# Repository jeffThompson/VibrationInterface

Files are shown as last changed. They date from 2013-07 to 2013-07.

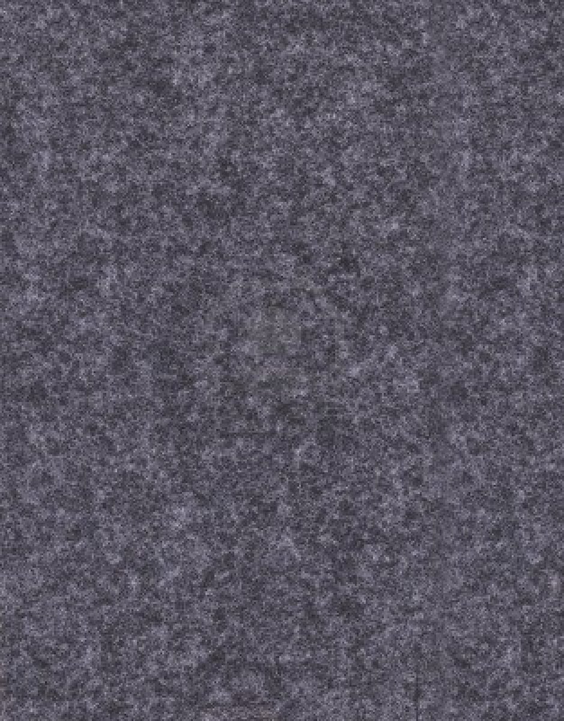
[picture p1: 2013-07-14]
LasercutPartsCADFiles/CAD_Model/FeltTexture.jpg

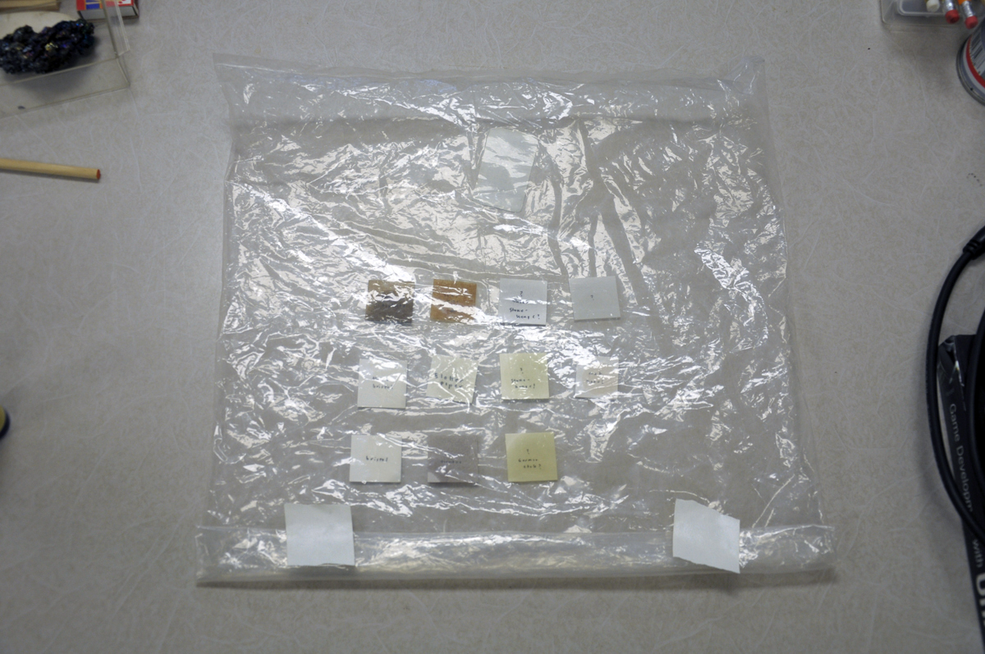
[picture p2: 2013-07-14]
ProcessPhotos/ScentImpregnationTest-02.jpg

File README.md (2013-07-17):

Vibration Interface

Vibration Interface
==================

A vibration interface for the Arduino, with example applications.

1. `LasercutPartsCADFiles` includes all files for building the interface, with files for cutting using Ponoko.
2. `LevelGenerationTimeTest` is a small app for testing how quickly the Arduino can generate a 2d array and randomly walk through it - used to optimize the included Mesa game.
3. `Mesa` is an example application for the interface where a player navigates an algorithmically-generated mesa, avoiding the cliff's edge.
4. `ProcessPhotos` includes documentation of the development process for this project.
5. `Simon` is a similar to the classic game of the same name, where the player must match an ever-lengthening pattern of directions. Instead of colored lights and sounds, this game uses the four vibration directions.

For required parts, see the `VibrationInterface_BOM.csv` and open in Excel (or a text editor), or [view the latest version in Google Docs](https://docs.google.com/spreadsheet/ccc?key=0ApWbqo450AfRdGZGZERDV3J2ZkhOYmNZS2k5c2tVR1E#gid=0).

Created with generous assistance from Harvestworks' Cultural Innovation Fund program.

\- \- \-

\[ all resources available under [Creative Commons BY-NC-SA license](http://creativecommons.org/licenses/by-nc-sa/3.0/) - feel free to use but [please let me know](http://www.jeffreythompson.org) \]

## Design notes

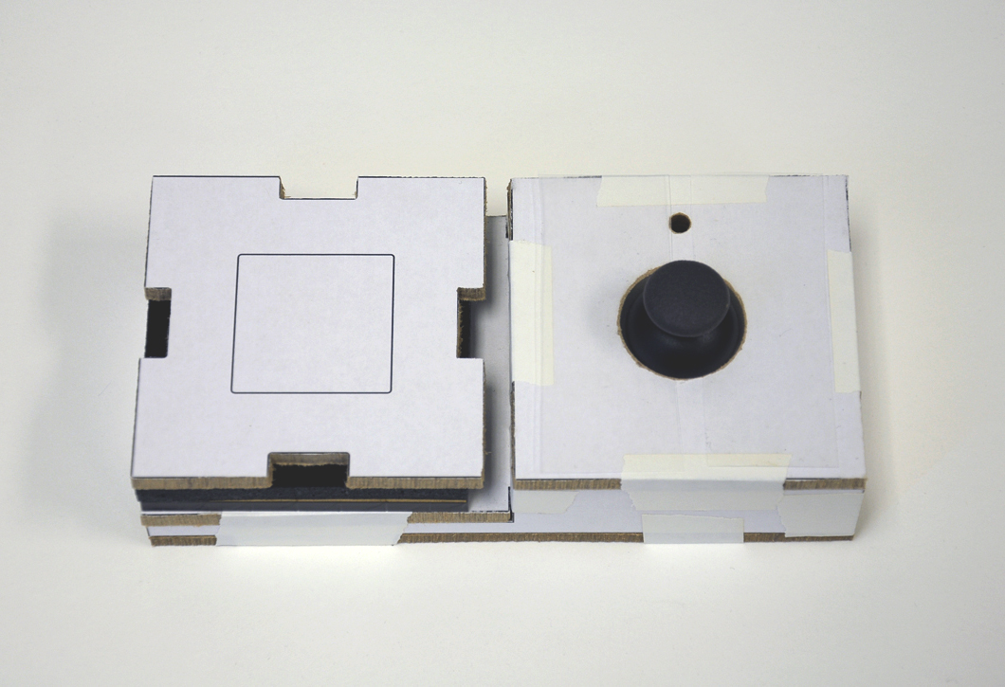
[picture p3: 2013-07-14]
ProcessPhotos/VibeBoard_WithInterface.jpg

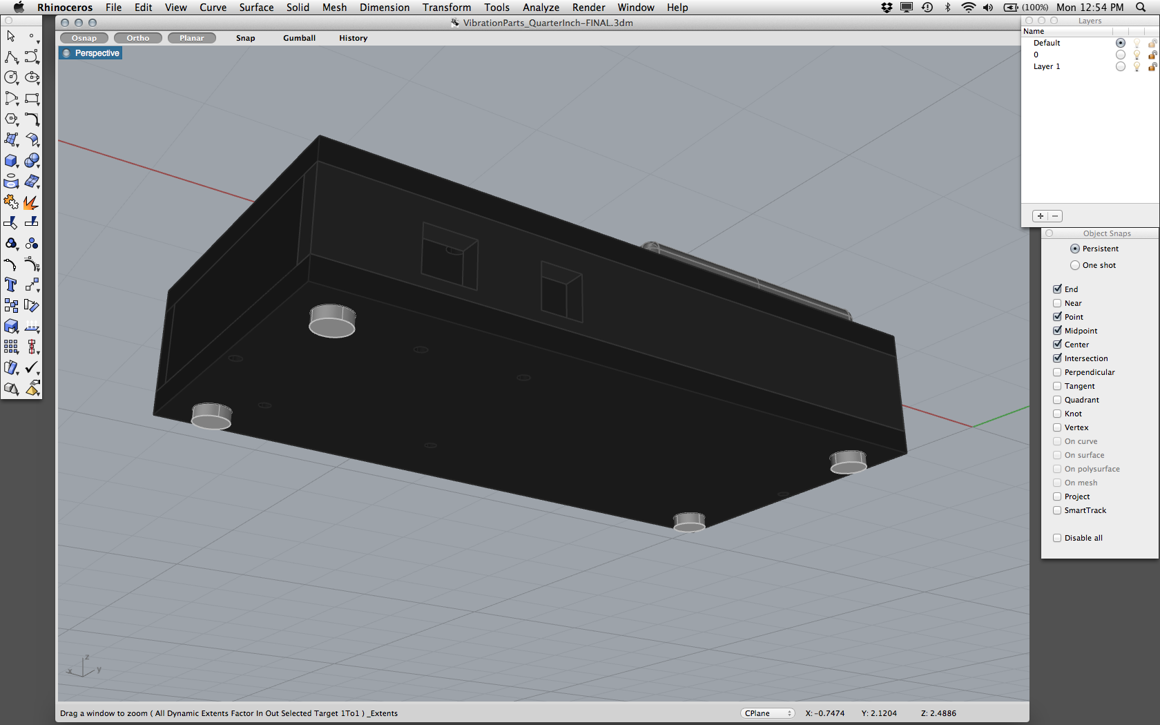
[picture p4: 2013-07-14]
ProcessPhotos/Final3dModel_Bottom.png

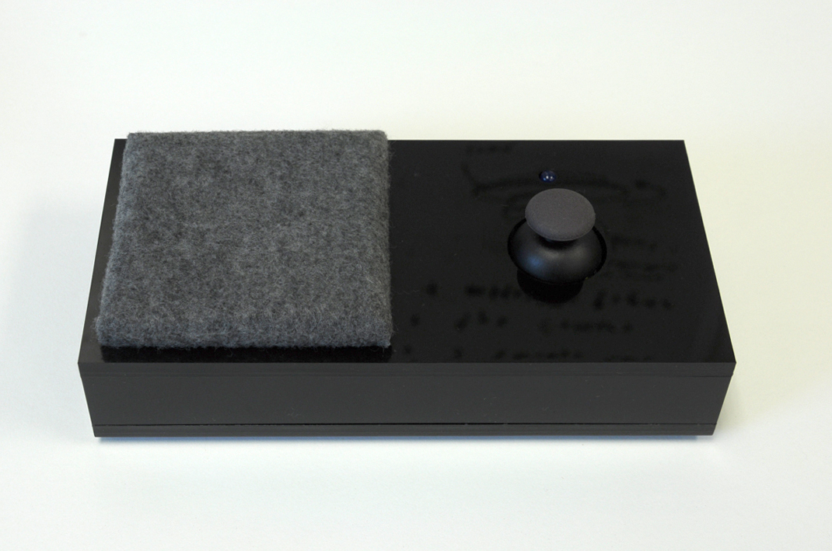
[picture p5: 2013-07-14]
ProcessPhotos/FinalPrototype.jpg

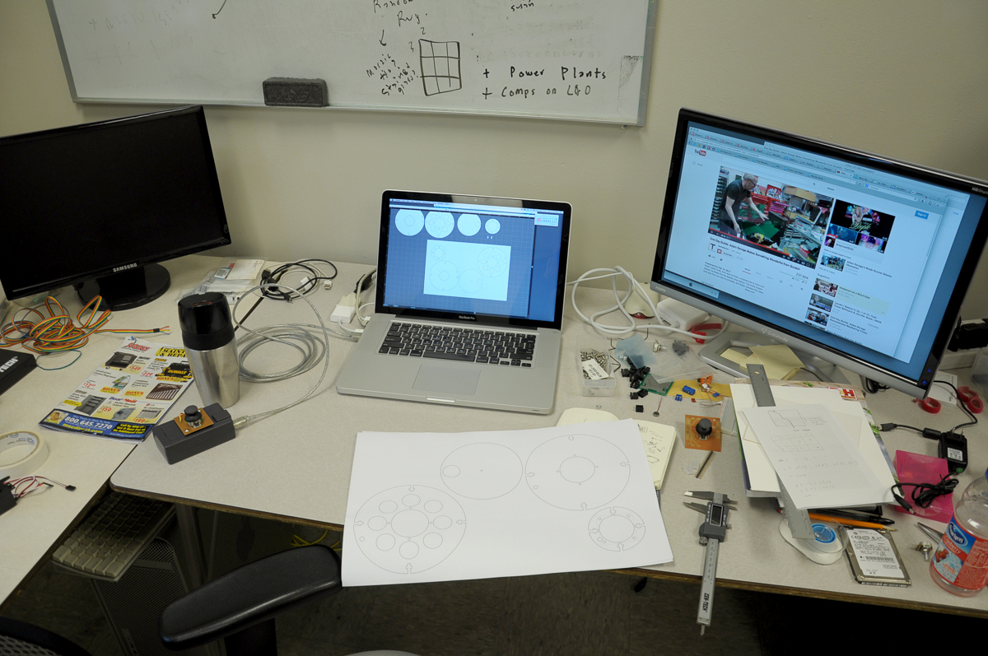
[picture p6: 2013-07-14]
ProcessPhotos/StudioInProcess.jpg

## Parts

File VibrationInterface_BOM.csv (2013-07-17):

Exported from a Google Doc: https://docs.google.com/spreadsheet/ccc?key=0ApWbqo450AfRdGZGZERDV3J2ZkhOYmNZS2k5c2tVR1E#gid=0
DESCRIPTION | $ EA | QTY | $ TOTAL | VENDOR | PART # | URL
Thumb joystick | $3.95 | 1 | $3.95 | SparkFun | COM-09032 | https://www.sparkfun.com/products/9032
Ribbon cable, 6 wire, 15 feet | $2.95 | 1 | $2.95 | SparkFun | CAB-10646 | https://www.sparkfun.com/products/10646
5mm blue LED | $0.50 | 1 | $0.50 | SparkFun | COM-11372 | https://www.sparkfun.com/products/11372
Breakaway male header (straight) | $1.50 | 2 | $3.00 | SparkFun | PRT-00116 | https://www.sparkfun.com/products/116
Arduino (lasercut parts designed for Uno, but Leonardo will work too) | $29.95 | 1 | $29.95 | SparkFun | DEV-11021 | https://www.sparkfun.com/products/11021
USB A/B cable | $3.95 | 1 | $3.95 | SparkFun | CAB-00512 | https://www.sparkfun.com/products/512
Clear heatshrink tubing, 1/8" x 4' | $4.19 | 1 | $4.19 | Digikey | KY018C-ND | http://www.digikey.com/scripts/DKSearch/dksus.dll?Detail&itemSeq=129182024&uq=635016143281570651
Vibration motor, flat coin | $3.99 | 4 | $15.96 | Digikey | 28821-ND | http://www.digikey.com/scripts/DKSearch/dksus.dll?Detail&itemSeq=129182080&uq=635016143281570651
Resistor (SMD 1210, 10k) - for button and/or standalone Arduino | $0.33 | 1 | $0.33 | Digikey | P10KVCT-ND | http://www.digikey.com/scripts/DKSearch/dksus.dll?Detail&itemSeq=129214700&uq=635016143281570651
Haptic vibration shield for Arduino (must order in sets of 3 - see Git for source files) | $10.84 | 3 | $32.52 | OSH Park |  | https://github.com/jeffThompson/HapticVibrationShield
#4 x 1/2" stainless steel bolt** | $0.05 | 2 | $0.10 | McMaster | 91772A110 | http://www.mcmaster.com/#machine-screw-fasteners/=nhd3yk
#4 stainless steel nut** | $0.03 | 2 | $0.06 | McMaster | 90730A005 | http://www.mcmaster.com/#hex-nuts/=nhd2ng
#4 x 5/16" stainess steel machine screw** | $0.05 | 4 | $0.20 | McMaster | 92470A109 | http://www.mcmaster.com/#tapping-screws/=nhd1l6
Nylon spacer (#4 screw, 1/8" high, 3/16" OD)** | $0.07 | 2 | $0.14 | McMaster | 94639A610 | http://www.mcmaster.com/#unthreaded-spacers/=nhd544
Rubber feet (clear, 1/2" dia x 9/64" high)** | $0.07 | 4 | $0.28 | McMaster | 95495K113 | http://www.mcmaster.com/#adhesive-backed-bumpers/=nhd9rx
Stainless steel hex screw for 1/4" acrylic pieces (.21" head dia)** | $0.03 | 4 | $0.14 | McMaster | 92949A108 | http://www.mcmaster.com/#socket-head-cap-screws/=n072yu
Haptic motor driver IC (from Mouser or a free sample from TI) | $1.70 | 1 | $1.70 | Mouser | DRV2603RUNR | http://www.mouser.com/ProductDetail/Texas-Instruments/DRV2603RUNR/
Note: for a full datasheet you must file a request with TI (bummer)
"Craft" felt sheet for interface surface (1 sheet at 9x12") | $0.95 | 1 | $0.95 | Craft store |  | ... and lasercut yourself: suggested settings - power 5%, speed 20%, ppi 500 at 5 passes to cut cleanly, 1 to etch the surface
Foam block for interface (3x3x1.5") |  | 1 |  | Fabric store |  | "Esterfoam" or upholstery foam works best
Lasercut parts (1/4" acrylic or masonite - Ponoko file prints 2 sets!) | $33.00 | 1 | $33.00 | Ponoko |  | Or cut it yourself: suggested settings for 1/4" acrylic - power 100%, speed 3.8%, ppi 250 at 4-5 passes
**note: these McMaster parts only come in boxes of 100
TOTAL |  |  | $133.87
UNUSED BUT INTERESTING PARTS
Retention e-ring, 1/4" shaft** | $0.06 | 2 | $0.11 | McMaster | 97421A300 | http://www.mcmaster.com/#catalog/119/3248/=mymkkg
Set screw shaft collar, 1/4" diameter, black-oxide finish | $0.90 | 5 | $4.50 | McMaster | 9414T6 | http://www.mcmaster.com/#catalog/119/1159/=mymm4s
Set screw shaft collar, 1/4" diameter, aluminum | $1.94 | 5 | $9.70 | McMaster | 9946K11 | http://www.mcmaster.com/#catalog/119/1159/=mymm4s
Conical compression spring, 0.625" length, 0.72/.375" dia, 0.04" wire | $2.75 | 3 | $8.25 | McMaster | 1692K58 | http://www.mcmaster.com/#compression-springs/=mymml3
Vibration motor (SMD) | $4.18 | 4 | $16.72 | Digikey | P14793CT-ND | http://www.digikey.com/scripts/DKSearch/dksus.dll?Detail&itemSeq=131692502&uq=635060559424879851
Vibration motor (capsule) | $4.99 | 4 | $19.96 | Digikey | 28822-ND | http://www.digikey.com/scripts/DKSearch/dksus.dll?Detail&itemSeq=131692497&uq=635060559424879851
PCB (6x9", positive, 1-sided) | $16.68 | 3 | $50.04 | Digikey | 473-1021-ND | http://www.digikey.com/scripts/DKSearch/dksus.dll?Detail&itemSeq=129182569&uq=635016143281570651
Capacitor (SMD 1210, 22pf) - for standalone Arduino | $0.74 | 4 | $2.96 | Digikey | 399-9402-1-ND | http://www.digikey.com/scripts/DKSearch/dksus.dll?Detail&itemSeq=129214596&uq=635016143281570651
MicroSD Shield | $14.95 | 1 | $14.95 | SparkFun | DEV-09802 | https://www.sparkfun.com/products/9802
IOIO board | $39.95 | 1 | $39.95 | SparkFun | DEV-11343 | https://www.sparkfun.com/products/11343
Barrel jack to 2-pin JST | $2.95 | 1 | $2.95 | SparkFun | TOL-08734 | https://www.sparkfun.com/products/8734
RGB LED, common cathode | $1.76 | 10 | $17.60 | SparkFun | COM-00105 | https://www.sparkfun.com/products/105
DC fan, 50x50x10mm | $4.95 | 2 | $9.90 | SparkFun | COM-09648 | https://www.sparkfun.com/products/9648
5-way tactile switch | $1.95 | 4 | $7.80 | SparkFun | COM-10063 | https://www.sparkfun.com/products/10063
Small servo (180 degree) | $8.95 | 2 | $17.90 | SparkFun | ROB-09065 | https://www.sparkfun.com/products/9065
Ribbon connector - 2x3 female | $0.32 | 10 | $3.20 | SparkFun | PRT-10651 | https://www.sparkfun.com/products/10651
Ribbon connector - 2x5 female | $0.45 | 10 | $4.50 | SparkFun | PRT-10650 | https://www.sparkfun.com/products/10650
Ribbon cable, 10 wire, 15 feet | $4.95 | 1 | $4.95 | SparkFun | CAB-10647 | https://www.sparkfun.com/products/10647
Vibration motor (flat, round - similar to Digikey 29921-ND) | $4.95 | 10 | $49.50 | SparkFun | ROB-08449 | https://www.sparkfun.com/products/8449
Omron snap action switch (for joystick - also on Mouser #D2F-L) | $1.76 | 12 | $21.12 | SparkFun | COM-00098 | https://www.sparkfun.com/products/98
Arduino Pro Micro (5V) | $19.95 | 1 | $19.95 | SparkFun | DEV-11098 | https://www.sparkfun.com/products/11098
DC barrel jack | $2.95 | 2 | $5.90 | SparkFun | PRT-10785 | https://www.sparkfun.com/products/10785
9V battery holder (drawer style, panel mount) | $4.95 | 2 | $9.90 | SparkFun | PRT-11368 | https://www.sparkfun.com/products/11368
Female headers | $1.50 | 3 | $4.50 | SparkFun | PRT-00115 | https://www.sparkfun.com/products/115

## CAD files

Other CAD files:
LasercutPartsCADFiles/VibrationParts_QuarterInch-FINAL.dwg
LasercutPartsCADFiles/FeltCover.dwg
LasercutPartsCADFiles/FeltCutTest.dwg
LasercutPartsCADFiles/CAD_Model/VibrationParts_QuarterInch-FINAL.3dm
LasercutPartsCADFiles/OlderFiles/VibrationBoard_3dModel.3dm
LasercutPartsCADFiles/OlderFiles/VibrationBoard_3dModel_QuarterInch.3dm
LasercutPartsCADFiles/OlderFiles/VibrationParts_QuarterInch_FloatingPad.3dm

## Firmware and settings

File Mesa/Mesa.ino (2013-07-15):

/*
MESA
 Jeff Thompson | 2013 | www.jeffreythompson.org
 
 The player walks around algorithmically-generated mesa. Move using the joystick,
 feel around you by pushing the button: vibration means ground, no vibration means
 we're at the edge.
 
 Created with generous support from Harvestworks' Cultural Innovation Fund program.
 
 For EagleCAD schematic/PCB files, lasercutting part files, and a BOM, see the 
 'LasercutPartsCADFiles' folder.
 
 Python/Arduino serial based on this tutorial and code by Neil Gershenfeld:
 http://web.media.mit.edu/~liningy/sub_work/lining.yao/design%20about/Tutorial_2.html
 
 TO DO - PROGRAMMING:
 + instructions how?
 + can serial debug be a secret that launches when plugged in? can it launch the terminal?

 */

const boolean debug = true;     // debug over serial USB?
const int visionDistance = 2;   // if printing, how far can we see?

// pins
const int horizPin = A1;        // horizontal joystick
const int vertPin = A0;         // vertical
const int buttonPin = 7;        // button from joystick
const int ledPin = 11;          // LED (must be a PWM pin)

const int upMotor = 10;         // motor pins
const int rightMotor = 5;
const int downMotor = 6;
const int leftMotor = 9;

// threshold for joystick
int lowThresh = 512-450;        // 512 = 1024/2
int highThresh = 512+450;

// level array (set dynamically in setup)
const int w = 28;               // level dimensions
const int h = 28;
const int numSteps = 700;       // # of steps to create the level
const int baseHeight = 20;      // starting tile height
const int heightInc = 2;        // +inc when traversing a tile
int level[h][w];                // the level itself!

// vibration variables
int neighborVibeTime = 250;     // time motors are on in ms 
int neighborOffTime = 40;       // time off between directions
int wallVibe[] = {              // wall hit pattern
  40, 30, 80, 30, 40 };

// other variables
int x,y;                                // current position in the level
int horiz, prevHoriz, vert, prevVert;   // joystick readings
int buttonState, prevButtonState;       // button reading

void setup() {

  createLevel();
  resetPlayerLocation();

  // setup button input
  pinMode(buttonPin, INPUT);
  prevButtonState = LOW;

  // setup motor and LED pins
  pinMode(upMotor, OUTPUT);
  pinMode(rightMotor, OUTPUT);
  pinMode(downMotor, OUTPUT);
  pinMode(leftMotor, OUTPUT);
  pinMode(ledPin, OUTPUT);

  // if specified, start serial connection for debugging
  if (debug) {
    Serial.begin(9600);
    printLevel();
  }
}

void loop() {

  // read joystick values
  readJoystick();

  // read button
  buttonState = digitalRead(buttonPin);
  if (buttonState != prevButtonState && buttonState == HIGH) {
    vibrateNeighbors();
  }
  prevButtonState = buttonState;

  // LED to current terrain height
  analogWrite(ledPin, map(level[y][x], 0,255, 0,50));
}

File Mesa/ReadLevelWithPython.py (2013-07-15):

#
# READ LEVEL WITH PYTHON
# Jeff Thompson | 2013 | www.jeffreythompson.org
#
# Launches a simple Python app that reads the nearby
# tiles as a debugging/cheating GUI :)
#
# Arguments:
# 1. serial port (to get, type "ls /dev/tty.*" into the Terminal)
# 2. port speed (default 9600)
#
# Based code by:
# Neil Gershenfeld
#
# Via this tutorial:
# http://web.media.mit.edu/~liningy/sub_work/lining.yao/design%20about/Tutorial_2.html

import serial, sys

# read arguments,
if (len(sys.argv) != 3):
   print "Arguments: ReadLevelWithPython.py serial_port port_speed"
   sys.exit()
port = sys.argv[1]
speed = int(sys.argv[2])

# setup serial connection
ser = serial.Serial(port,speed)
ser.setDTR()
ser.flushInput()

# read incoming serial data!
while True:							# run forever
   x = ser.readline()		# read line from Arduino
   print x							# print (easy)!

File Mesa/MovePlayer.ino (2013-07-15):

void movePlayer() {

  // right
  if (horiz < lowThresh) {
    x += 1;
    if (x > w-1) x = 0;

    if (level[y][x] == 0) {
      fallVibration(rightMotor);
      setup();
    }
    else {
      stepVibration(rightMotor);
      if (debug) printLevel();
    }
  }

  // left
  else if (horiz > highThresh) {
    x -= 1;
    if (x < 0) x = w-1;

    if (level[y][x] == 0) {
      fallVibration(leftMotor);
      setup();
    }
    else {
      stepVibration(leftMotor);
      if (debug) printLevel();
    }
  }

  // up
  if (vert > highThresh) {
    y -= 1;
    if (y < 0) y = h-1;

    if (level[y][x] == 0) {
      fallVibration(upMotor);
      setup();
    }
    else {
      stepVibration(upMotor);
      if (debug) printLevel();
    }
  }

  // down
  else if (vert < lowThresh) {
    y += 1;
    if (y > h-1) y = 0;

    if (level[y][x] == 0) {
      fallVibration(downMotor);
      setup();
    }
    else {
      stepVibration(downMotor);
      if (debug) printLevel();
    }
  }
}

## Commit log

2013-07-15 Added updated PCB images
2013-07-17 Added BOM exported from Google Doc
    [VibrationInterface_BOM.csv]
